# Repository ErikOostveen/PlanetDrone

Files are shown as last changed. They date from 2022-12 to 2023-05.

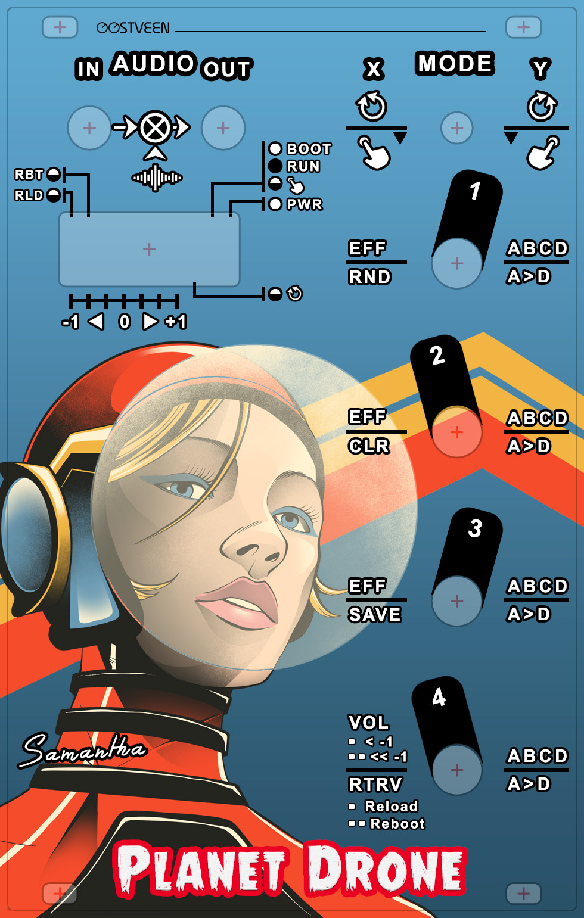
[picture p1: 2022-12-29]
Front_Panels__Cutout_and_Design/3 - Example_CutOut_and_Artwork_Combined/Planet_Drone_Module_11112022.jpg

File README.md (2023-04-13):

# Planet Drone

Planet Drone Module

<br/>&#9642; Introduction

Sound has a powerful effect on the brain and can be used as a tool to relax and destress. When we listen to soothing sounds, our brain waves slow down, leading to a state of relaxation. This can be particularly useful for individuals who struggle with anxiety, stress, and insomnia.

One way that sound relaxes the brain is through the process of entrainment. This refers to the tendency of our brain waves to sync up with external rhythms, such as the sound of music or the sound of ocean waves. When we listen to these kinds of rhythmic sounds, our brain waves naturally slow down and become more synchronized, leading to a state of relaxation.

Another way that sound relaxes the brain is through its ability to distract us from our thoughts and worries. When we focus on a pleasant sound, such as the sound of a waterfall or the sound of a favorite piece of music, it can help to draw our attention away from any negative or stressful thoughts that may be occupying our minds. This can be especially helpful for individuals who tend to ruminate or worry excessively.

In addition to its ability to relax the brain, sound can also have a number of other beneficial effects on our physical and mental well-being. For example, research has shown that listening to music can lower blood pressure, reduce heart rate, and even boost the immune system. It can also help to improve our mood, increase feelings of happiness and pleasure, and even reduce the perception of pain.

Overall, the relaxing power of sound is undeniable. Whether it's through entrainment, distraction, or any of its other beneficial effects, sound can be a powerful tool for helping us to relax and de-stress. So the next time you're feeling overwhelmed or anxious, consider turning on some soothing sounds and letting them work their magic on your brain.

&#9642; Summary

Planet Drone is an Open Source Raspberry PI Eurorack-Module project, which uses the <a href="https://supercollider.github.io/" target="_blank">SuperCollider</a> platform to generate distinctive and captivating music drones.

Planet Drone consists of a triad of complementary, electronically-identical, Eurorack modules each wielding a unique set of extraordinary music drones (patches).

On power-up, the module selects a random patch for you to enjoy listening to and manipulate using the four encoder knobs. Multiply this drone-power by 3 (i.e. 3 modules) and you can imagine the wonderful soundscapes you can create!

Each module comes with a selection of patches written in the SuperCollider real time audio synthesis programming language (sclang). If you are up for a challengem you can edit existing patches or even write your own.

Collect or build all three modules and get droning!

&#9642; PCBWay

Visit <a href="https://www.pcbway.com/project/shareproject/Planet_Drone_48e0f221.html">PCBWay</a> for more PCB details.

&#9642; Demos

 Check out my <a href="https://www.youtube.com/watch?v=LrP70BMYkts&list=PL4E2GvauW2Yx9BJaXl0h-VZrDoGBAw_IS" target="_blank">Planet Drone channel</a> on YouTube to view an ever growing list of drone demos.

&#9642; Raspberry PI image files

 Download the latest Planet Drone 
<a href="https://drive.google.com/drive/folders/15fokcHUIsh2QlJMY6MdCen8XLZz8E1yO?usp=share_link" target="_blank">Raspberry PI image files</a> from Google Drive. You'll need a 32GB Micro SD card for each of the three images/modules.

&#9642; Online Manual

 Check out the <a href="http://www.erikoostveen.co.uk/Planetdrone.html" target="_blank">Online Manual</a>.

Enjoy! Erik

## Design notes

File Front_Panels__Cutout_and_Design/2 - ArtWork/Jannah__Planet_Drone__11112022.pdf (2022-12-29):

IN AUDIO OUT | X MODE Y

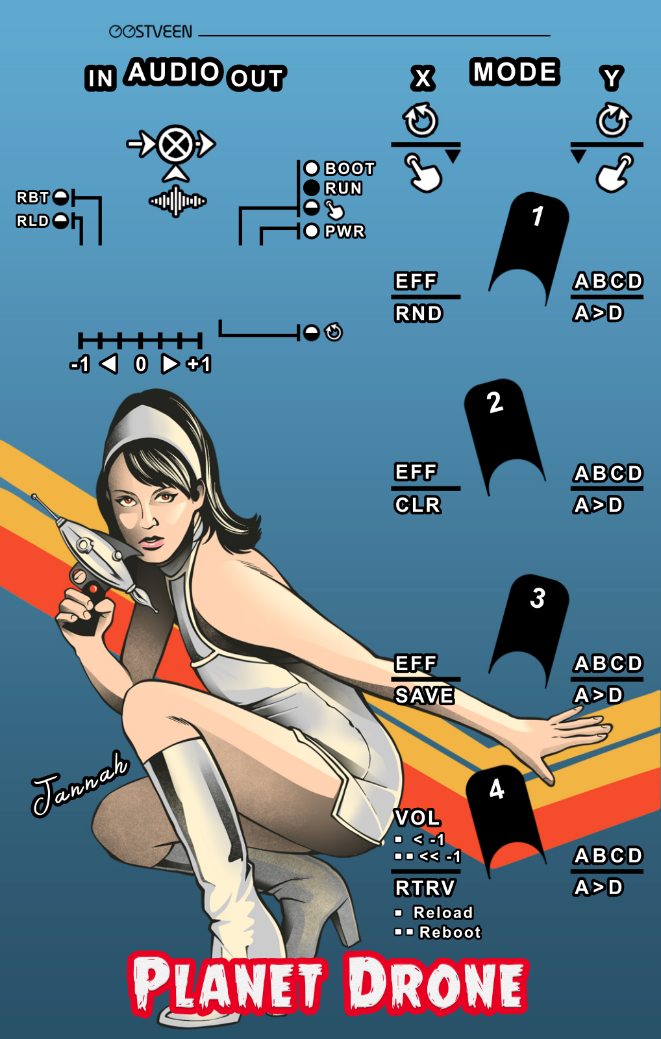
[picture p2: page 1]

# Jannah

RND

EFF

CLR

EFF

SAVE

EFF

Reload
Reboot

RTRV

<-1
<<-1

VOL

A>D

ABCD

A>D

ABCD

A>D

ABCD

A>D

ABCD

-1 0 +1

1

2

3

4

# PlanetDrone

●

●

●

BOOT
RUN
PWR RLD

RBT

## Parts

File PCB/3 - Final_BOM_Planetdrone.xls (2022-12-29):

Item # | Designator | Qty | Manufacturer | Mfg Part # | Description / Value | Vendor Part # | Package/Footprint | Actual Purchase Mfg Part # | Note
1 | 10SEGMENTLEDBAR | 1 | TE Connectivity | DS1009-20AT1NX-0A2 | DS1009-20AT1NX-0A2 | C72118 | DIP-20_L25.4-W7.1-P2.54-LS8.5-BL | 1-2199298-6
2 | C1,C2,C3,C4,C5,C6,C7,C8 | 8 | FH | 0805B153K101NT | 15nF | E24856 | 0805
3 | CNV1 | 1 | JacobsParts | DCMOD-H | Converter | B078C7ZS74 | MINI360 BUCKCONVERTER
4 | ENCODER1,ENCODER2,ENCODER3,ENCODER4 | 4 | ALPSALPINE | EC11E15244B2 | EC11E15244B2 | C470754 | SW-TH_EC11XXXXXXXX | PEC11R-4220F-S0024
5 | P1,P5 | 2 | BOOMELE | 2.54-1*2P母 | Header-Female-2.54_1x2 | C49661 | HDR-1X2/2.54
6 | POWER | 1 | BOOMELE | 2.54-2*8P简牛 | HDR-IDC-2.54-2X8P | C3406 | IDC-TH_16P-P2.54_C3406
7 | Q1 | 1 | onsemi | BC846AMTF | 2N2222 | C184441 | SOT-23-3_L2.9-W1.3-P1.90-LS2.4-BR | BC846ALT1G | BC846ALT1G instead of 2N2222
8 | RASPBERRYPIZERO2W | 1 | CONNFLY | 2.54-2*20P母 | Header-Female-2.54_2x20 | C50982 | HDR-TH_40P-P2.54-V-F-R2-C20-S2.54 | DS1023-2*20SF11
9 | STEREOJACK1,STEREOJACK2 | 2 |  | Thonk | THONKICONN_JACK_GREEN HOLE |  | THONKICONN_JACK_GREEN_HOLE
10 | TOGGLESWITCH1 | 1 |  |  | 9x2mm Micro Toggle Switch |  | 9X4MM TOGGLE MICRO SWITCH
11 | U2,U3,U4 | 3 | CTS |  | 0402 8P4R Resistor Array 220E |  | 0402 8P4R RESISTOR ARRAY | 741X083221JP
12 | U5,U6,U7 | 3 | CTS |  | 0402 8P4R Resistor Array 10K |  | 0402 8P4R RESISTOR ARRAY | 741X083103JP
13 | U8 | 1 |  | CJMCU-1334 | CJMCU-1334 |  | CJMCU-1334_FP

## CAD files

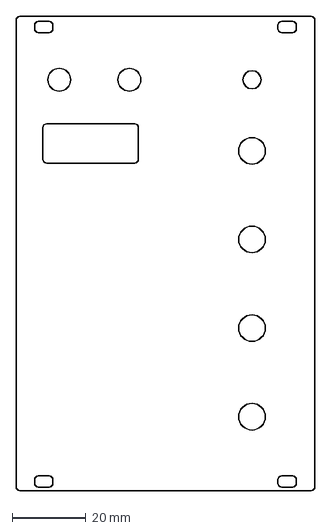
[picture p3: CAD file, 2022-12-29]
Front_Panels__Cutout_and_Design/1 - CutOut/Front_Panel_CUTOUT_25092022.dxf
80.9 x 128.4 mm

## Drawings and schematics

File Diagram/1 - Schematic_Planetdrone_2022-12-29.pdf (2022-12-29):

# STEREOJACK1SLEVE/GND ¹ RING ² TIP 3

# STEREOJACK2 SLEVE/GND ¹ RING ² TIP 3

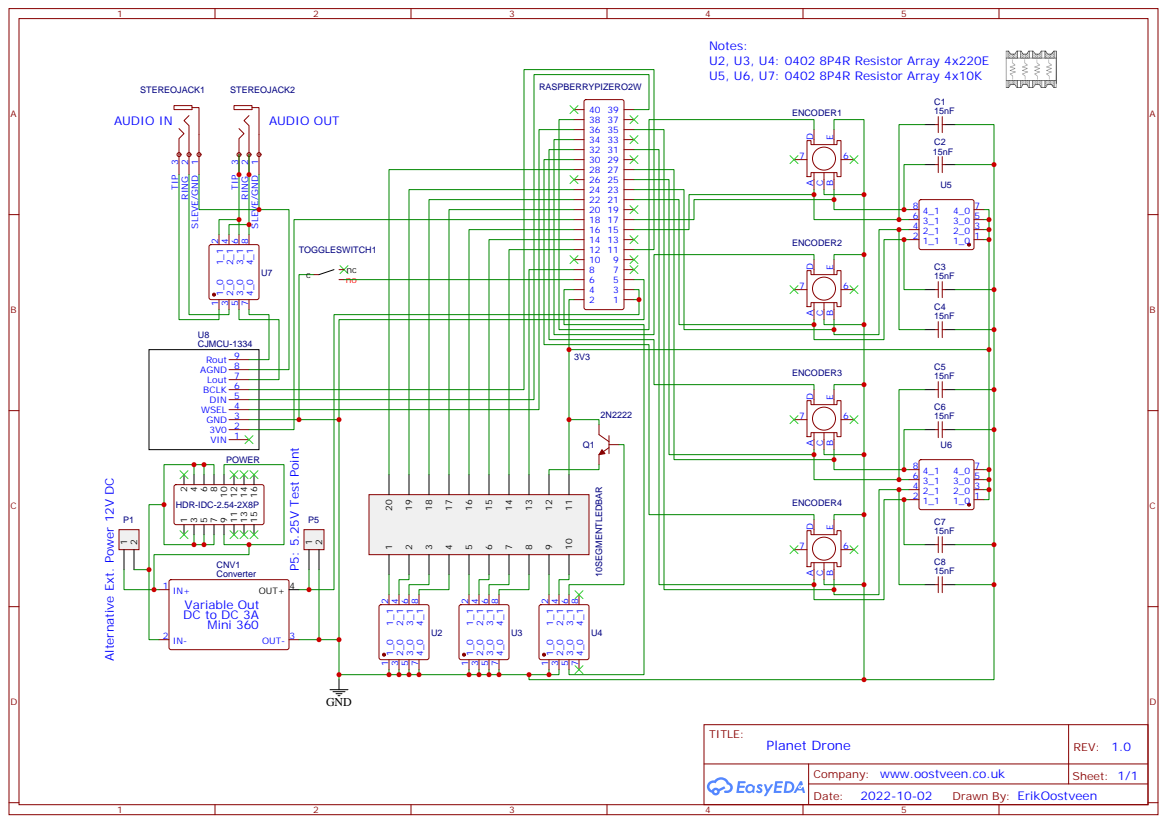
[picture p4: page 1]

Alternative Ext. Power 12V DC

Company: www.oostveen.co.uk

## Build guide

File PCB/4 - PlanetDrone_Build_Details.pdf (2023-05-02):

## Toggle Switch (ON-NONE-ON) (1x)

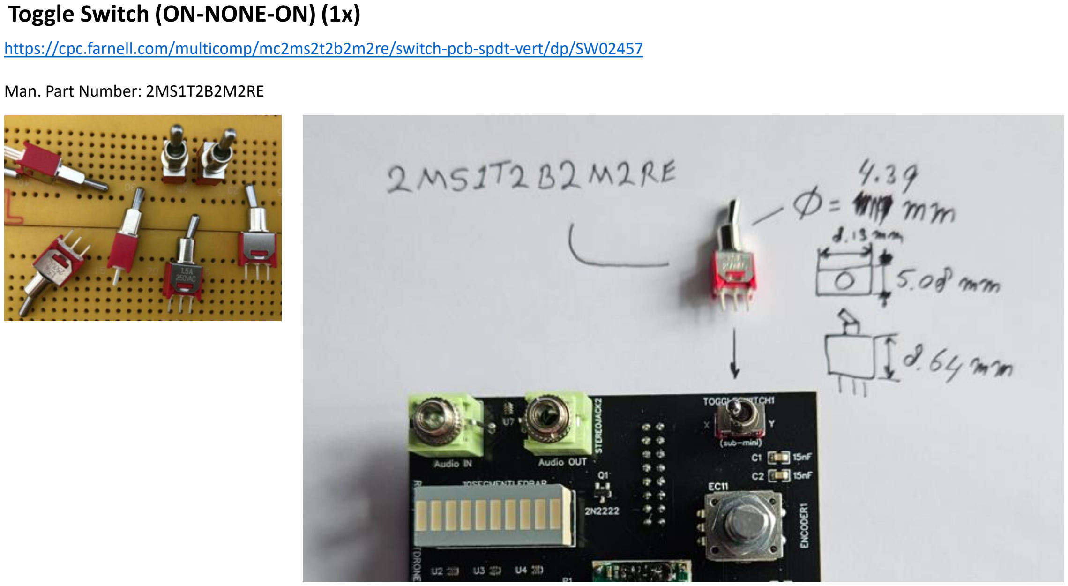
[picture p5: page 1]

https://cpc.farnell.com/multicomp/mc2ms2t2b2m2re/switch-pcb-spdt-vert/dp/SW02457

Man. Part Number: 2MS1T2B2M2RE https://uk.rs-online.com/web/p/mechanical-rotary-encoders/7377767

Man. Part Number: PEC11R-4220F-S0024

## Encoders (4x)

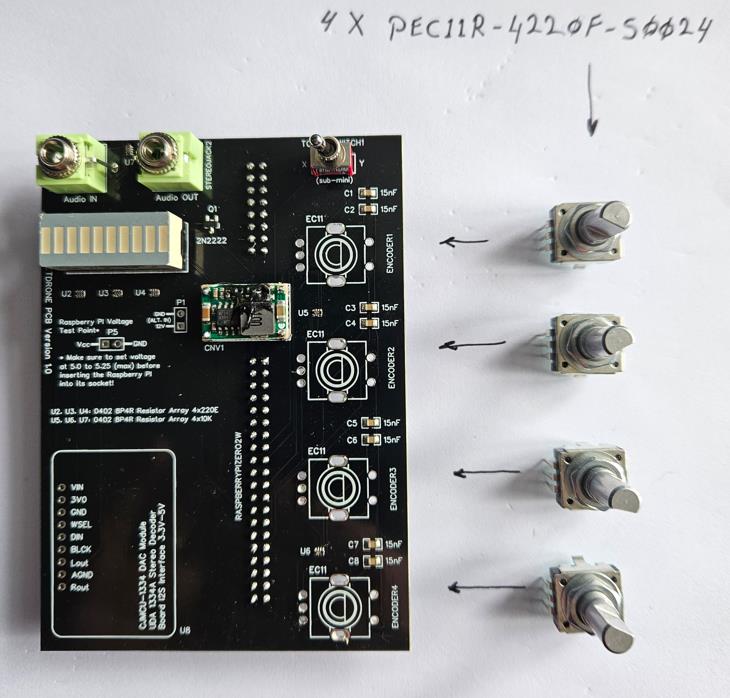
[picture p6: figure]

## Audio Board (1x)

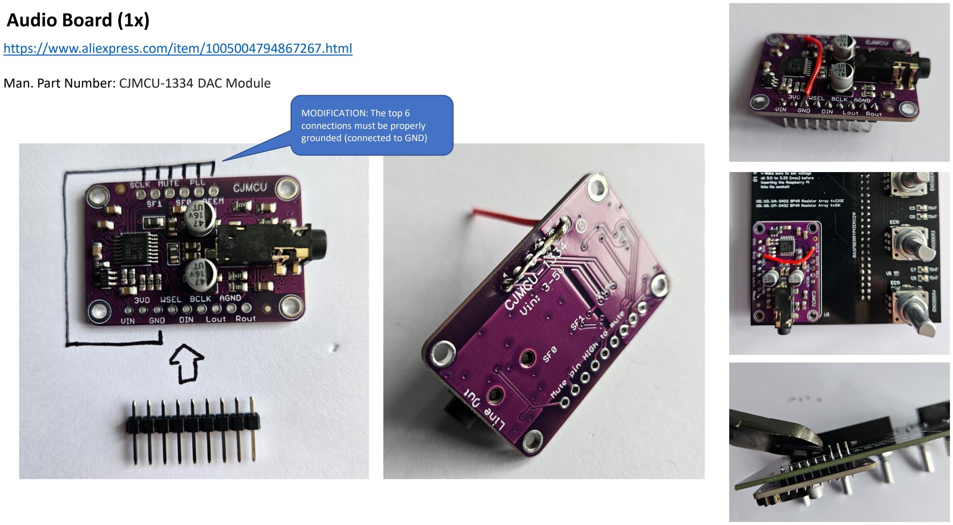
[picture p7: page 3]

https://www.aliexpress.com/item/1005004794867267.html

Man. Part Number: CJMCU-1334 DAC Module

MODIFICATION: The top 6
connections must be properly grounded (connected to GND)

https://www.thonk.co.uk/shop/3-5mm-jacks/

Green Thonkiconn Stereo 3.5mm Audio Jacks

## Stereo 3.5mm Sockets (2x)

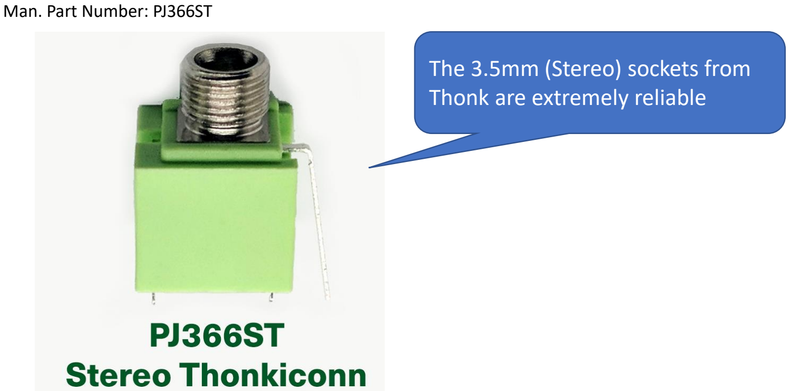
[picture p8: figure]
Man. Part Number: PJ366ST; The 3.5mm (Stereo) sockets from Thonk are extremely reliable

## Step-down board (1x)

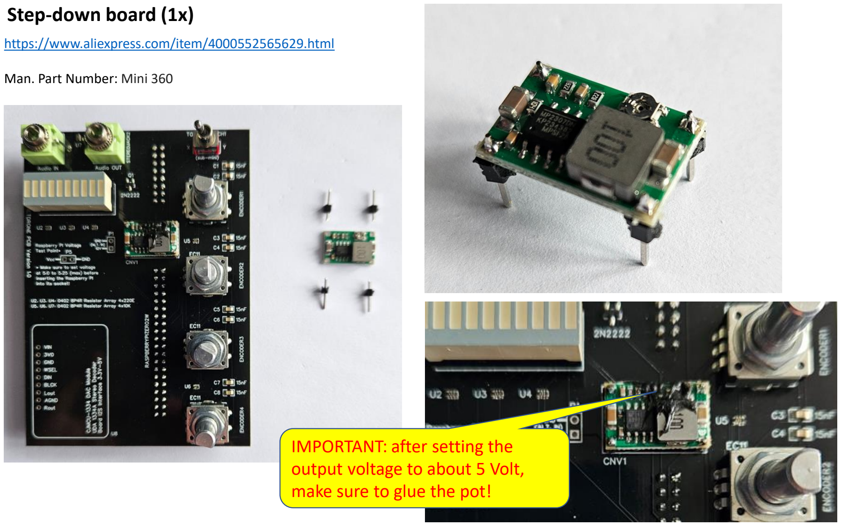
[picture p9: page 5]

https://www.aliexpress.com/item/4000552565629.html

Man. Part Number: Mini 360

### IMPORTANT: after setting the

output voltage to about 5 Volt,

### make sure to glue the pot!

## Step-down board (measure output voltage)

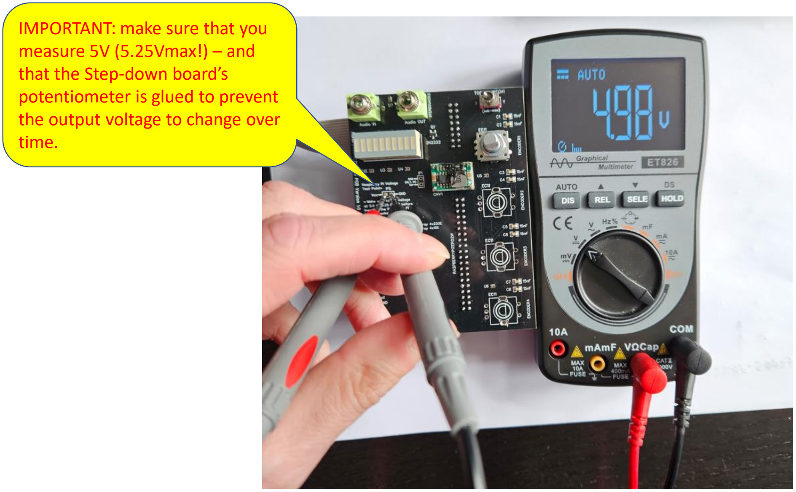
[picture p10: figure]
IMPORTANT: make sure that you measure 5V (5.25Vmax!) – and that the Step-down board’s potentiometer is glued to prevent the output voltage to change over time.

## 10LEDs Bar Graph

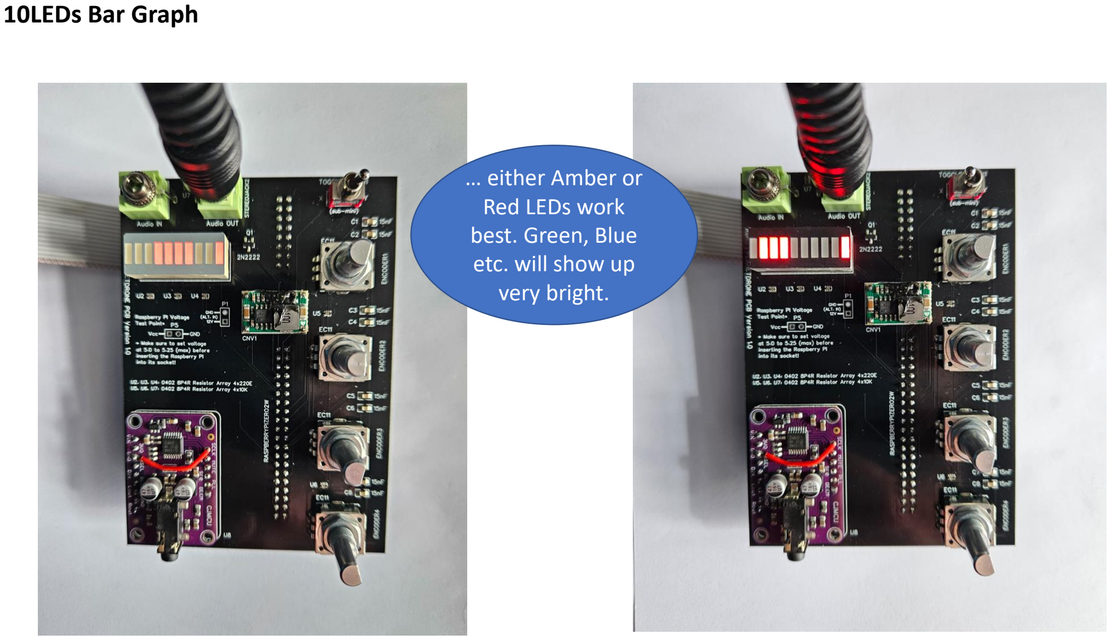
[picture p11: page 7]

### … either Amber or Red LEDs work best. Green, Blue etc. will show up

very bright.

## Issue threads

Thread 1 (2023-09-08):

RP2040

interstaller555, 2023-09-08:
Is there any chance this would run on an RP2040?

ErikOostveen, 2023-09-08:
Hi.

I am afraid not.

The Raspberry Pi Pico’s RP2040 processor lacks the required hardware to run UNIX-like operating systems. You need this isnother to run the audio synthesis engine SuperCollider.

interstaller555, 2023-09-20:
Awesome! Thank you! I assume a Zero W (1) will work...

ErikOostveen, 2023-09-20:
Go for Zero 2W

interstaller555, 2023-09-20:
fair - I can't find them for the advertised 15.00.... here they are 55.00+ (USD)

interstaller555, 2023-09-20:
would you be willing to recompile your images for the other zero 2 w varients?

ErikOostveen, 2023-09-20:
Unfortunately, at the moment, I don't have the time to revisit this project

interstaller555, 2023-09-20:
sorry! would you be willing to publish your SC patches?

ErikOostveen, 2023-09-20:
I am working on putting together a bundle - and will upload as a zip

interstaller555, 2023-09-21:
AMAZING! Thanks!

interstaller555, 2023-10-11:
Hello! I understand you're super busy - i'm hoping you've had a chance to put that bundle together...

interstaller555, 2023-10-11:
hi, thanks! this appears to be for slimshader....

ErikOostveen, 2023-10-11:
Check out this link

https://drive.google.com/file/d/1PFOfANgB5veCpvLe6QFGAPmz-UQjpRc2/view?usp=drivesdk

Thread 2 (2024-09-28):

Ways to use it with USB DAC

lorenzoantei, 2024-09-28:
Hi. I tried to use it with a USB DAC.
```
$ aplay -l
**** List of PLAYBACK Hardware Devices ****
card 0: sndrpihifiberry [snd_rpi_hifiberry_dac], device 0: HifiBerry DAC HiFi pcm5102a-hifi-0 [HifiBerry DAC HiFi pcm5102a-hifi-0]
  Subdevices: 1/1
  Subdevice #0: subdevice #0
card 1: UA5 [EDIROL UA-5], device 0: USB Audio [USB Audio]
  Subdevices: 1/1
  Subdevice #0: subdevice #0
```
I tried to edit ~/.jackdrc as follow:
```
$ cat .jackdrc
/usr/local/bin/jackd -R -P 75 -T -d alsa -d hw:1 -r 44100 -p 256 -n 3
```

If I boot and tried to play something:
```
$ aplay /usr/share/sounds/alsa/Front_Center.wav
ALSA lib pcm_dmix.c:1075:(snd_pcm_dmix_open) unable to open slave
aplay: main:830: audio open error: Device or resource busy
```

```
$ ./reload.sh
compiling class library...
	Found 738 primitives.
	Compiling directory '/usr/local/share/SuperCollider/SCClassLibrary'
	Compiling directory '/usr/local/share/SuperCollider/Extensions'
	Compiling directory '/home/pi/.local/share/SuperCollider/Extensions'
	numentries = 1111582 / 12540684 = 0.089
	4231 method selectors, 2964 classes
	method table size 8250384 bytes, big table size 50162736
	Number of Symbols 11784
	Byte Code Size 332335
	compiled 455 files in 1.17 seconds

Info: 4 methods are currently overwritten by extensions. To see which, execute:
MethodOverride.printAll

compile done
localhost : setting clientID to 0.
internal : setting clientID to 0.
Class tree inited in 0.1 seconds

*** Welcome to SuperCollider 3.13.0-dev. *** For help type ctrl-c ctrl-h (Emacs) or :SChelp (vim) or ctrl-U (sced/gedit).
'/quit' message sent to server 'localhost'.
'/quit' message sent to server 'localhost'.
Booting server 'localhost' on address 127.0.0.1:57110.
Faust: supercollider.cpp: sc_api_version = 3
Faust: FaustJPverbRaw numControls=11
Found 0 LADSPA plugins
Faust: supercollider.cpp: sc_api_version = 3
Faust: FaustGreyholeRaw numControls=7
Cannot connect to server socket err = No such file or directory
Cannot connect to server request channel
jackdmp 1.9.22
Copyright 2001-2005 Paul Davis and others.
Copyright 2004-2016 Grame.
Copyright 2016-2022 Filipe Coelho.
jackdmp comes with ABSOLUTELY NO WARRANTY
This is free software, and you are welcome to redistribute it
under certain conditions; see the file COPYING for details
JACK server starting in realtime mode with priority 75
self-connect-mode is "Don't restrict self connect requests"
Cannot connect to server socket err = No such file or directory
Cannot connect to server request channel
creating alsa driver ... hw:1|hw:1|256|3|44100|0|0|nomon|swmeter|-|32bit
configuring for 44100Hz, period = 256 frames (5.8 ms), buffer = 3 periods
ALSA: final selected sample format for capture: 16bit little-endian
ALSA: use 3 periods for capture
ALSA: final selected sample format for playback: 16bit little-endian
ALSA: use 3 periods for playback
JackDriver: client name is 'SuperCollider'
SC_AudioDriver: sample rate = 44100.000000, driver's block size = 256
JackDriver: connected  system:capture_1 to SuperCollider:in_1
JackDriver: connected  system:capture_2 to SuperCollider:in_2
JackDriver: connected  SuperCollider:out_1 to system:playback_1
JackDriver: connected  SuperCollider:out_2 to system:playback_2
SuperCollider 3 server ready.
JackDriver: max output latency 17.4 ms
Requested notification messages from server 'localhost'
localhost: server process's maxLogins (1) matches with my options.
localhost: keeping clientID (0) as confirmed by server process.
Shared memory server interface initialized
server 'localhost' disconnected shared memory interface
Shared memory server interface initialized
server 'localhost' disconnected shared memory interface
Shared memory server interface initialized
JackEngine::XRun: client = SuperCollider was not finished, state = Running
```

lorenzoantei, 2024-09-28:
// after boot
$ aplay /usr/share/sounds/alsa/Front_Center.wav
ALSA lib pcm_dmix.c:1075:(snd_pcm_dmix_open) unable to open slave
aplay: main:830: audio open error: Device or resource busy
pi@PlanetDrone-Samantha:~ $ ./killall.sh
pi@PlanetDrone-Samantha:~ $ aplay /usr/share/sounds/alsa/Front_Center.wav
Playing WAVE '/usr/share/sounds/alsa/Front_Center.wav' : Signed 16 bit Little Endian, Rate 48000 Hz, Mono

ErikOostveen, 2024-09-28:
Getting jackd to work can be quite a struggle.
Perhaps my SuperCollider on UniHiker gives better insight:

https://github.com/ErikOostveen/SuperColliderOnUniHiker

lorenzoantei, 2024-09-29:
> Getting jackd to work can be quite a struggle. Perhaps my SuperCollider on UniHiker gives better insight:
>
> https://github.com/ErikOostveen/SuperColliderOnUniHiker

Done!
I follow your guide without built SuperCollider and add this to autostart.sh script:
```
# ...
# export DISPLAY=:0.0

export JACK_NO_AUDIO_RESERVATION=1 # EDIT

# Retrieve .scd patches
# ...

```

Closed 2024-09-29.
